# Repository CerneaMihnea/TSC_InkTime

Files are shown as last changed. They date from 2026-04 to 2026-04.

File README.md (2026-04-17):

# InkTime Watch
---

## Descriere generala

InkTime este un ceas inteligent bazat pe microcontroller-ul **nRF52840** , care utilizeaza un display E-Paper (cerneala electronica) pentru afisarea orei si a altor informatii. Proiectul include design complet de schematic, PCB pe 4 straturi si modelare 3D a ansamblului, realizate in Autodesk Fusion.

Principalele caracteristici:
- Microcontroller nRF52840 cu Bluetooth 5.0 si procesor ARM Cortex-M4
- Display E-Paper conectat prin SPI
- Accelerometru/IMU pentru detectia miscarii (step counter, wake-on-wrist)
- Baterie LiPo cu circuit de incarcare dedicat
- Regulator DC/DC pentru tensiune stabila de 3.3V
- Fuel Gauge pentru monitorizarea nivelului bateriei
- Driver haptic pentru feedback vibrotactil
- Protectie ESD pe linia USB-C
- Conectivitate USB-C pentru incarcare si programare
- 3 butoane fizice pentru interactiune

---

## Diagrama bloc

```
                         +-------------------+
                         |    Baterie LiPo   |
                         +--------+----------+
                                  |
                         +--------v----------+
                         |  LiPo Charger     |  <-- USB-C (5V / VBUS)
                         |  BQ25180YBGR      |
                         +--------+----------+
                                  | VBAT (3.7-4.2V)
                         +--------v----------+
                         |  Fuel Gauge        |  <-- I2C --> nRF52840
                         |  MAX17048G+T10     |
                         +--------+----------+
                                  |
                         +--------v----------+
                         |  DC/DC Regulator  |  <-- I2C --> nRF52840
                         |  RT6160AWSC       |
                         +--------+----------+
                                  | 3V3
          +-----------------------+-----------------------+
          |                       |                       |
+---------v---------+   +---------v---------+   +---------v---------+
|   nRF52840 (U1)   |   |  ESD Protection   |   |   Butoane (x3)    |
|   Microcontroller |   |  USBLC6-2SC6Y     |   |   EVP-AKE31A      |
+---------+---------+   +-------------------+   +-------------------+
          |
    +-----+------+------+------+
    |            |      |      |
+---v---+  +----v--+  +-v---+ +-v---------+
| SPI   |  |  I2C  |  | SWD | | GPIO/ANT  |
+---+---+  +---+---+  +-----+ +-----------+
    |          |
+---v---+   +--+--+--+--+
|E-Paper|   | IMU | Haptic|
|Display|   |BMA423|DRV2605|
+-------+   +-------+-----+
```

---

## Bill of Materials (BOM)

| Cantitate | Componenta | Descriere | Referinta | 
|:---:|:---:|:---:|:---:|
| 1 | nRF52840 | Microcontroller ARM Cortex-M4, BT 5.0 | U1 | 
| 1 | BQ25180YBGR | LiPo Charger IC, 8-DSBGA | IC1 | 
| 1 | DRV2605YZFR | Haptic Driver ERM/LRA, 9-BGA | IC2 |
| 1 | BMA423 | IMU Accelerometru triaxial 12-bit | IC3 |
| 1 | MAX17048G+T10 | Fuel Gauge 1-Cell ModelGauge | U3 | 
| 1 | RT6160AWSC | Buck-Boost DC/DC Regulator I2C, 15-WL-CSP | IC9 | 
| 1 | USBLC6-2SC6Y | ESD Protection TVS Diode, SOT-23-6 | D3 | 
| 1 | KH-TYPE-C-16P | Conector USB-C 16 pini | J4 |
| 1 | 503480-2400 | Conector FPC/FFC 0.5mm 24 circuite | J1 | 
| 1 | DMG2305UX-7 | P-Channel MOSFET 20V/4.2A SOT-23 | Q2 | 
| 1 | SI1308EDL-T1-GE3 | N-Channel MOSFET 30V/1.5A SC-70 | Q3 | 
| 3 | MBR0530 | Dioda Schottky 30V/500mA SOD-123 | D1, D2, D5 | 
| 3 | EVP-AKE31A | Buton tactil SMD ultra-subtire | SW_DN, SW_ENT, SW_UP | 
| 1 | 2450AT18B100E | Antena 2.45GHz SMD | ANT1 | 
| 1 | FTC252012SR47MBCA | Inductor SMD 0.47uH 2016 | L7 | 
| 1 | 744043680 | Inductor SMD 68uH WE-TPC | L5 |
| 1 | TC2030-IDC | Conector Tag-Connect 6 pini SWD | J2 |
| 1 | X1 (32MHz) | Crystal 32MHz 2016 SMD | X1 |
| 1 | X2 (32.768kHz) | Crystal 32.768kHz 3215 SMD | X2 | 
| ~50 | Condensatoare SMD | 0201/0402, diverse valori (1pF - 22uF) | Cx | 
| ~15 | Rezistoare SMD | 0201, diverse valori (2.2Ω - 10kΩ) | Rx |
| ~4 | Inductoare SMD | 0402, diverse valori (3.9nH - 15nH, 10uH) | Lx |
| 14 | Test Pad TP20R | Test pad-uri SMD 2mm | TP_* |
| 1 | Solder Jumper SJ | Jumper SMD | SJ1 |

---

## Descrierea functionalitatii hardware

## Funcționalitate hardware

### Interfețe de comunicație
- **I2C**: LiPo Charger, DC/DC, IMU, Fuel Gauge, Haptic Driver  
- **SPI**: E-Paper Display Connector  

### Componente și roluri

- **nRF52840**  
  Microcontroller-ul principal care coordonează întreaga funcționalitate a plăcii.

- **IMU (Accelerometru)**  
  Măsoară accelerația pe cele trei axe.

- **LiPo Charger**  
  Responsabil pentru încărcarea bateriei.

- **DC/DC**  
  Stabilizator de tensiune ce furnizează 3.3V stabili întregii plăci.

- **E-Paper Drive Circuit**  
  Controlează funcționarea display-ului E-Paper.

- **Fuel Gauge**  
  Monitorizează nivelul de încărcare al bateriei.

- **Haptic Driver**  
  Controlează vibrațiile actuatorului (shaker).

- **USB-C Connector**  
  Asigură interfața de conectare USB.

- **ESD Protection**  
  Protejează placa împotriva descărcărilor electrostatice.

---

## Pinii nRF52840

Tabelul de mai jos descrie alocarea pinilor microcontroller-ului:

| Pin nRF52840 | Semnal | Modul conectat | Interfata | Descriere |
|---|---|---|---|---|
| VDD | 3V3 | Alimentare | - | Alimentare la 3.3V |
| VSS | GND | Masa | - | Referinta de masa |
| P0.02/AIN0 | SCK | E-Paper Display | SPI | Clock serial SPI |
| P0.03/AIN1 | MOSI | E-Paper Display | SPI | Date catre display (Master Out Slave In) |
| P0.05/AIN3 | CS | E-Paper Display | SPI | Chip Select display |
| P0.15 | EPD_RST | E-Paper Display | GPIO | Reset display |
| P0.16 | EPD_DC | E-Paper Display | GPIO | Data/Command select |
| P0.17 | EPD_BUSY | E-Paper Display | GPIO | Stare ocupata display |
| P0.06 | SCL | IMU, LiPo Charger, DC/DC, Fuel Gauge, Haptic | I2C | Clock linie I2C |
| P0.07 | SDA | IMU, LiPo Charger, DC/DC, Fuel Gauge, Haptic | I2C | Date linie I2C |
| P0.08 | IMU_INT2 | BMA423 | GPIO | Intrerupere 2 accelerometru |
| P1.08 | IMU_INT1 | BMA423 | GPIO | Intrerupere 1 accelerometru |
| P0.10/NFC2 | FUELGAUGE_ALT | MAX17048 | GPIO | Alarma nivel scazut baterie |
| P0.11 | CHARGER_PG | BQ25180 | GPIO | Semnal Power Good charger |
| P0.12 | HAPTIC_EN | DRV2605 | GPIO | Enable driver haptic |
| P0.13 | BTN_UP | SW_UP | GPIO | Buton sus |
| P0.14 | BTN_ENT | SW_ENT | GPIO | Buton enter/confirmare |
| P1.02 | BTN_DN | SW_DN | GPIO | Buton jos |
| D+ | USB_DP | USB-C / ESD | USB | Date USB diferentiale pozitive |
| D- | USB_DM | USB-C / ESD | USB | Date USB diferentiale negative |
| VBUS | 5V USB | LiPo Charger | - | Alimentare 5V din USB |
| SWDIO | SWDIO | TC2030-IDC (J2) | SWD | Date programare/debug |
| SWDCLK | SWDCLK | TC2030-IDC (J2) | SWD | Clock programare/debug |
| SWO | SWO | TC2030-IDC (J2) | SWD | Trace output |
| P0.18/RESET | RESET | TC2030-IDC (J2) | GPIO | Reset hardware microcontroller |
| ANT | RF | 2450AT18B100E | RF | Antena Bluetooth 2.4GHz |
| XC1, XC2 | XTAL_32M | X1 (32 MHz) | Clock | Sursa de ceas principala |
| XL1, XL2 | XTAL_32K | X2 (32.768 kHz) | Clock | Sursa de ceas RTC (low power) |
| DEC1-DEC5 | GND | - | - | Condensatoare decuplare regulatoare interne |

---

## Design PCB si modelare 3D

### Stackup PCB — 4 straturi

Placa a fost realizata pe **4 straturi** pentru a asigura integritate de semnal buna si o rutare curata:

| Strat | Rol |
|---|-----|
| Top (L1) | Rutare semnal + componente SMD |
| L2 | Plan de masa (GND) |
| L3 | Plan de 3.3V (VCC) |
| Bottom (L4) | Rutare semnal secundar |

Avantajele acestui stackup:
- Planul de masa L2 ofera un return path scurt pentru toate semnalele de pe L1
- Planul de 3.3V L3 reduce impedanta de alimentare si EMI
- Via-urile de semnal au return path minim intre straturi adiacente

### Decizii de design notabile

**Antena si decupaj PCB**: Antena 2450AT18B100E este pozitionata in coltul inferior al placii. Sub jumatatea neconectata electric a antenei, s-a realizat un **decupaj al substratului** (cutout) pentru a imbunatati performanta de radiatie si a evita absorbtia de semnal RF de catre materialul FR4.

**Via-in-pad**: Pentru componentele BGA (BQ25180, RT6160, DRV2605, MAX17048) cu pitch mic, s-au folosit **via-in-pad** — via-uri plasate direct sub pad-urile componentelor. Aceasta tehnica permite rutarea semnalelor in spatiu limitat, dar necesita umplere cu rasina (plugged vias) pentru a asigura planitate la lipire.

**Test pad-uri**: Sunt prevazute 14 test pad-uri (TP20R) pentru toate semnalele importante: 3V3, VBAT, GND, SDA, SCL, SWDCLK, SWDIO, SWO, RESET, VREG. Acestea faciliteaza testarea si depanarea dupa asamblare.

**Conexiuni baterie si shaker**: Bateria LiPo si motorul haptic (shaker) sunt conectate la PCB prin fire sudate pe test pad-urile dedicate (TP_VBAT, TP_VBAT_GND, respectiv pad-urile haptic driver-ului).

### Modelare 3D

Modelarea 3D a ansamblului ceasului a fost realizata in **Autodesk Fusion** si include:

- **PCB 3D** cu toate componentele plasate si orientate corect
- **Baterie LiPo** — model la nivel mediu de detaliu, cu fire de legatura rosu (+) si negru (-)
- **Display E-Paper** — model cu cadru verde si suprafata activa neagra, cu conector FPC/FFC
- **Shaker (motor haptic)** — model cilindric cu fire rosu si albastru
- **Carcasa** — carcasa inferioara si cadru superior de retentie display, fabricate din material negru
- **Exploded View** — vedere explodata verticala a ansamblului complet
- **Animatie** exploded view (disponibila in folderul Mechanical)

---

## Imagini

### Schematic

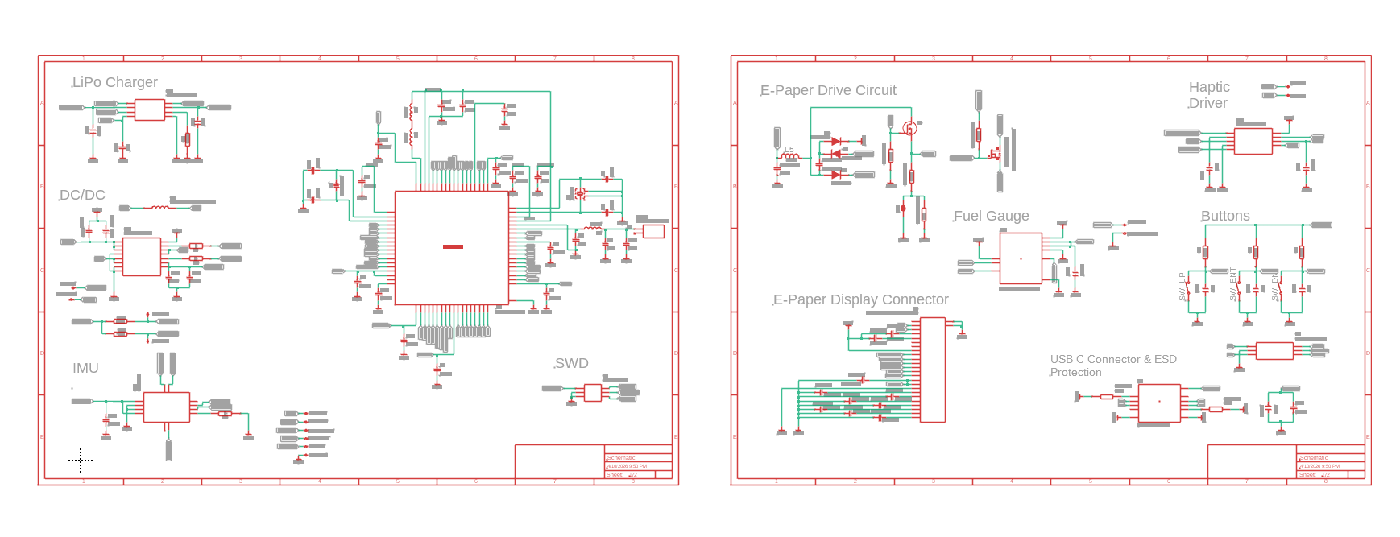
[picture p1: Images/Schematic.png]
Schematic


### PCB 2D

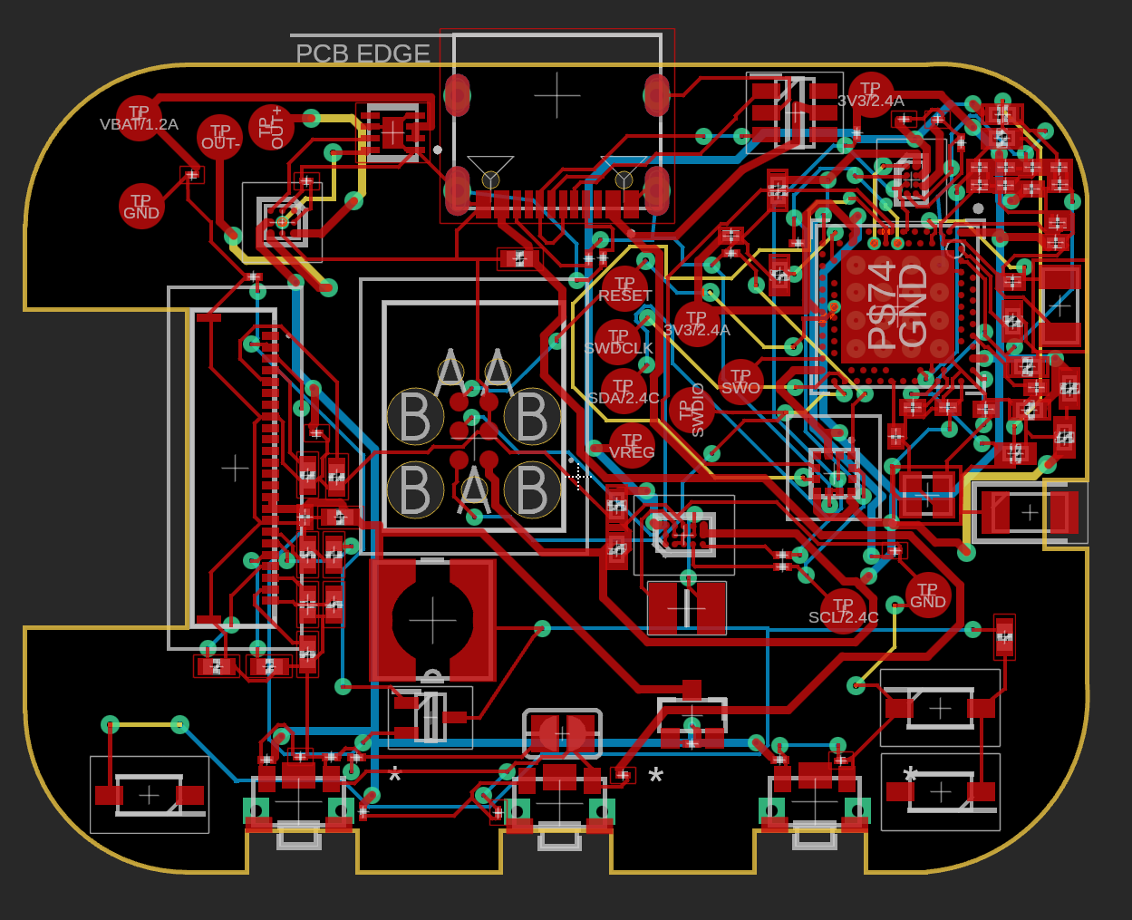
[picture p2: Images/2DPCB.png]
PCB 2D


### PCB 3D

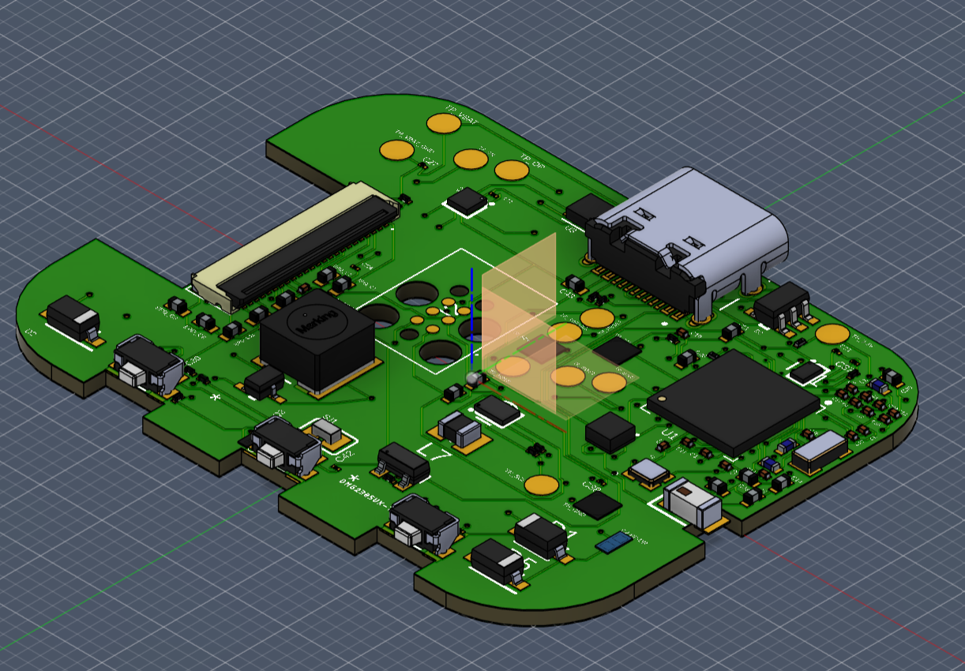
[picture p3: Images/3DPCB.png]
PCB 3D


### Baterie

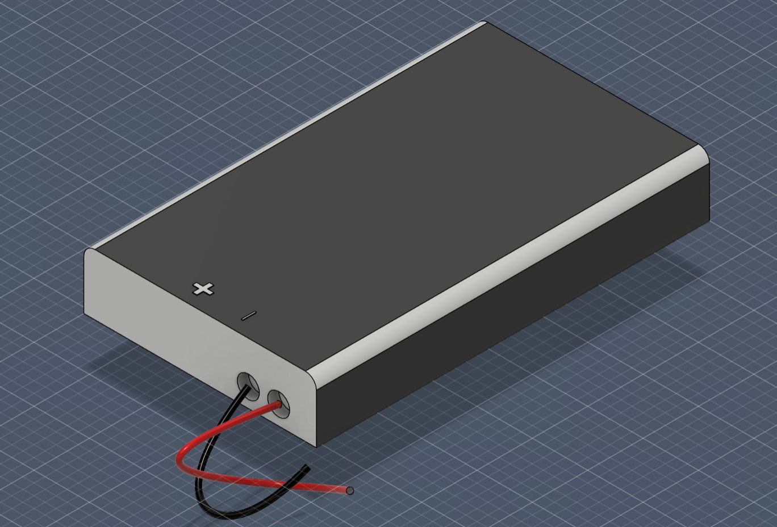
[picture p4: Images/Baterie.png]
Baterie


### Display E-Paper

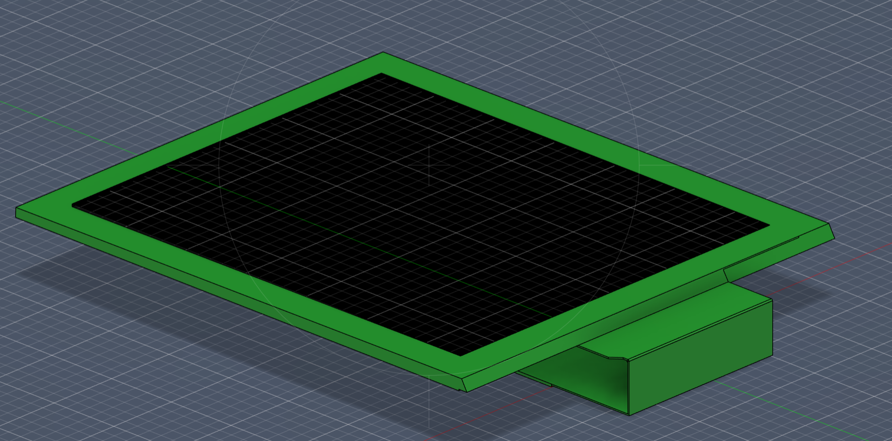
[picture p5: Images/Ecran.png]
Display


### Shaker (Motor Haptic)

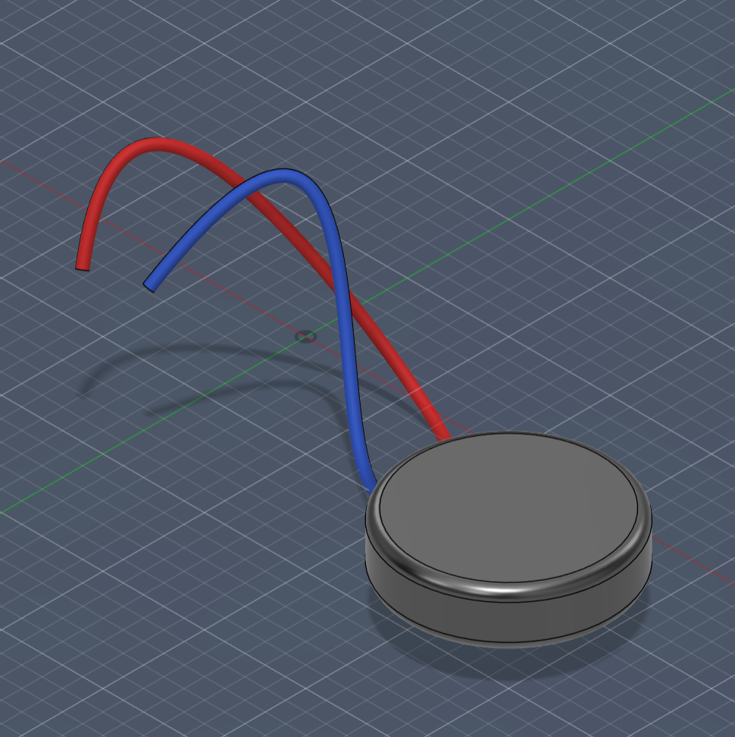
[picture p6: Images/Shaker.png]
Shaker


### Exploded View

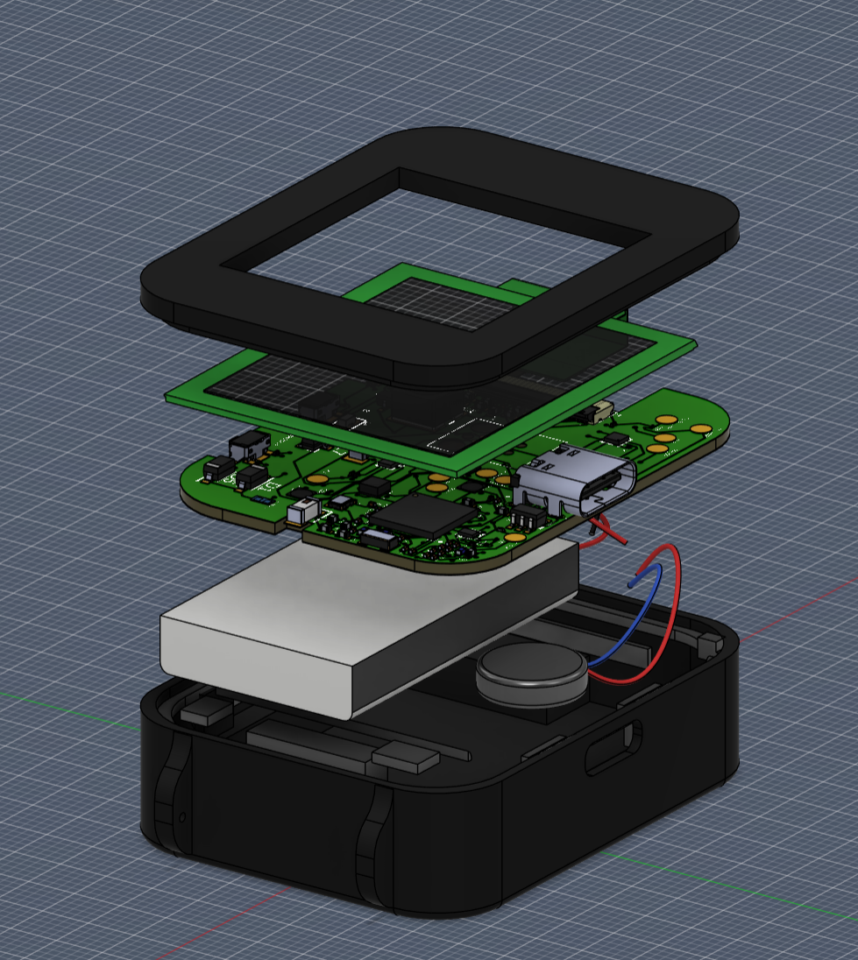
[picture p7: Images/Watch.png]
Exploded View


## Diagrama de sistem — SVG

Diagrama bloc interactiva este disponibila in fisierul `inktime_diagram.svg` din radacina proiectului.

---

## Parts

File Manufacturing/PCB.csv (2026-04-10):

Qty | Value | Device | Package | Parts | Description | ARROW_PART_NUMBER | ARROW_PRICE-STOCK | AVAILABILITY | CHECK_PRICES | COPYRIGHT | DESCRIPTION | DIGI-KEY_PART_NUMBER_1 | DIGI-KEY_PART_NUMBER_2 | DIGI-KEY_PART_NUMBER_3 | HEIGHT | JLCPCB | MANUFACTURER_NAME | MANUFACTURER_PART_NUMBER | MF | MFR_NAME | MOUSER_PART_NUMBER | MOUSER_PRICE-STOCK | MP | PACKAGE | POPULARITY | PRICE | PROD_ID | PURCHASE-URL | SNAPEDA_LINK | TP_SIGNAL_NAME | VALUE
1 |  | ESP32_C6_LIBRARY_7_JUMPER_SJ | ESP32_C6_LIBRARY_7_JUMPER_SJ | SJ1 | SMD solder JUMPER |  |  |  |  |  |  |  |  |  |  |  |  |  |  |  |  |  |  |  | 3
3 | 0 | CPF0201D7K68C1_CPF0201D7K68C1 | CPF0201D7K68C1_0201 | R2, R3, R4 | 7.68k 0201 Thin Film Surface Mount Fixed Resistor +/-0.5% 0.031W CPF0201D7K68C1
4 | 0.1uF | GRM011R60J152KE01L_2_GRM011R60J152KE01L | GRM011R60J152KE01L_2_CAPC0201X13N | C23, C27, C34, C42 | Check availability |  |  | In Stock | https://www.snapeda.com/parts/GRM011R60J152KE01L/Murata/view-part/?ref=eda |  | SMD Capacitor X5R(EIA) with Capacitance: 1500pF Tol. 10%. Rated Voltage: 6.3Vdc |  |  |  |  |  |  |  | Murata |  |  |  | GRM011R60J152KE01L | 0201 Murata |  | None |  |  | https://www.snapeda.com/parts/GRM011R60J152KE01L/Murata/view-part/?ref=snap
1 | 0.1uF/50V | NORDIC_NRF_3_CAPACITOR_0201_L | NORDIC_NRF_3_RESC0201_L | EPD_C5 | Generic chip capacitor
1 | 0.47 | CPF0201D7K68C1_CPF0201D7K68C1 | CPF0201D7K68C1_0201 | R1_EP_DR | 7.68k 0201 Thin Film Surface Mount Fixed Resistor +/-0.5% 0.031W CPF0201D7K68C1
1 | 1.0µF | NORDIC_NRF_3_CAPACITOR_0402_L | NORDIC_NRF_3_RESC0402_L | C15 | Generic chip capacitor
5 | 100nF | NORDIC_NRF_3_CAPACITOR_0201_L | NORDIC_NRF_3_RESC0201_L | C5, C7, C8, C12, C19 | Generic chip capacitor
1 | 100pF | NORDIC_NRF_3_CAPACITOR_0201_L | NORDIC_NRF_3_RESC0201_L | C11 | Generic chip capacitor
6 | 10K | CPF0201D7K68C1_CPF0201D7K68C1 | CPF0201D7K68C1_0201 | R2_EP_DR, R5, R7, R8, R9, R_PWR_EPD | 7.68k 0201 Thin Film Surface Mount Fixed Resistor +/-0.5% 0.031W CPF0201D7K68C1
1 | 10uF | GRM011R60J152KE01L_2_GRM011R60J152KE01L | GRM011R60J152KE01L_2_CAPC0201X13N | C38 | Check availability |  |  | In Stock | https://www.snapeda.com/parts/GRM011R60J152KE01L/Murata/view-part/?ref=eda |  | SMD Capacitor X5R(EIA) with Capacitance: 1500pF Tol. 10%. Rated Voltage: 6.3Vdc |  |  |  |  |  |  |  | Murata |  |  |  | GRM011R60J152KE01L | 0201 Murata |  | None |  |  | https://www.snapeda.com/parts/GRM011R60J152KE01L/Murata/view-part/?ref=snap
1 | 10uF | NORDIC_NRF_3_CAPACITOR_0402_L | NORDIC_NRF_3_RESC0402_L | C24 | Generic chip capacitor
1 | 10uF | PERFECT_0402_CAP_0402 | PERFECT_0402_0402 | C1-EP-DR | 0402 (1005 Metric)
1 | 10µH | NORDIC_NRF_2_INDUCTOR_0402_L | NORDIC_NRF_2_RESC0402_L | L2 | Generic chip inductor
4 | 12pF | NORDIC_NRF_3_CAPACITOR_0201_L | NORDIC_NRF_3_RESC0201_L | C1, C2, C17, C18 | Generic chip capacitor
1 | 15nH | NORDIC_NRF_2_INDUCTOR_0402_L | NORDIC_NRF_2_RESC0402_L | L3 | Generic chip inductor
2 | 1pF | NORDIC_NRF_3_CAPACITOR_0201_L | NORDIC_NRF_3_RESC0201_L | C3, C4 | Generic chip capacitor
5 | 1uF | GRM011R60J152KE01L_2_GRM011R60J152KE01L | GRM011R60J152KE01L_2_CAPC0201X13N | C29, C30, C31, C32, C37 | Check availability |  |  | In Stock | https://www.snapeda.com/parts/GRM011R60J152KE01L/Murata/view-part/?ref=eda |  | SMD Capacitor X5R(EIA) with Capacitance: 1500pF Tol. 10%. Rated Voltage: 6.3Vdc |  |  |  |  |  |  |  | Murata |  |  |  | GRM011R60J152KE01L | 0201 Murata |  | None |  |  | https://www.snapeda.com/parts/GRM011R60J152KE01L/Murata/view-part/?ref=snap
1 | 1uF | NORDIC_NRF_3_CAPACITOR_0402_L | NORDIC_NRF_3_RESC0402_L | C39 | Generic chip capacitor
9 | 1uF/50V | PERFECT_0402_CAP_0402 | PERFECT_0402_0402 | EPD_C1, EPD_C2, EPD_C6, EPD_C7, EPD_C8, EPD_C9, EPD_C10, EPD_C11, EPD_C12 | 0402 (1005 Metric)
1 | 2.2 | CPF0201D7K68C1_CPF0201D7K68C1 | CPF0201D7K68C1_0201 | R_TYPE_SEL | 7.68k 0201 Thin Film Surface Mount Fixed Resistor +/-0.5% 0.031W CPF0201D7K68C1
3 | 2025-10-22_07-23-44_LIBRARY_EVP-AKE31ASW_EVP-AKE31A_PAN | 2025-10-22_07-23-44_LIBRARY_EVP-AKE31ASW_EVP-AKE31A_PAN | 2025-10-22_07-23-44_LIBRARY_SW_EVP-AKE31A_PAN | SW_DN, SW_ENT, SW_UP |  |  |  |  |  | Copyright (C) 2025 Ultra Librarian. All rights reserved. |  | P123437TR-ND | P123437CT-ND | P123437DKR-ND |  |  | Panasonic | EVP-AKE31A
1 | 20V/4.2A/52mO/1.4W | ESP32_C6_LIBRARY_4_ESP32_WROVER_SPARKFUN-DISCRETESEMI_MOSFET_PCH-DMG2305UX-7 | ESP32_C6_LIBRARY_4_ESP32_C6_LIBRARY_4_ESP32_C6_LIBRARY_4_ESP32_C6_LIBRARY_4_ESP32_WROVER_SPARKFUN-DISCRETESEMI_SOT23-3 | DMG2305UX-7 | P-channel MOSFETs |  |  |  |  |  |  |  |  |  |  |  |  |  |  |  |  |  |  |  |  |  | TRAN-14388 |  |  |  | 20V/4.2A/52mO/1.4W
2 | 22uF | NORDIC_NRF_3_CAPACITOR_0402_L | NORDIC_NRF_3_RESC0402_L | C25, C33 | Generic chip capacitor
1 | 2450AT18B100E | 2450AT18B100E_2450AT18B100E | 2450AT18B100E_ANTC3216X140N | ANT1 | Antennas 2.45GHz ANTENNA | 2450AT18B100E | https://www.arrow.com/en/products/2450at18b100e/johanson-dielectrics?utm_currency=USD&region=nac |  |  |  | Antennas 2.45GHz ANTENNA |  |  |  | 1.4mm |  | JOHANSON TECHNOLOGY | 2450AT18B100E |  |  | 609-2450AT18B100E | https://www.mouser.co.uk/ProductDetail/Johanson-Technology/2450AT18B100E?qs=yCnrNFeXz%252Bh5MFsFIXGZGA%3D%3D
1 | 3.9nH | NORDIC_NRF_2_INDUCTOR_0402_L | NORDIC_NRF_2_RESC0402_L | L1 | Generic chip inductor
1 | 32.768kHz | NORDIC_NRF_1_XTAL_32KHZ | NORDIC_NRF_1_XTAL_3215_N | X2
1 | 32MHz | NORDIC_NRF_XTAL_32MHZ | NORDIC_NRF_BT-XTAL_2016_N | X1
1 | 3K3 | ERA-1AEB3401C_CPF0201D7K68C1 | ERA-1AEB3401C_0201 | R17 | 7.68k 0201 Thin Film Surface Mount Fixed Resistor +/-0.5% 0.031W CPF0201D7K68C1
1 | 3k3 | ERA-1AEB3401C_CPF0201D7K68C1 | ERA-1AEB3401C_0201 | R18 | 7.68k 0201 Thin Film Surface Mount Fixed Resistor +/-0.5% 0.031W CPF0201D7K68C1
1 | 4.7uF | PERFECT_0402_CAP_0402 | PERFECT_0402_0402 | C43 | 0402 (1005 Metric)
1 | 4.7uF/25V | PERFECT_0402_CAP_0402 | PERFECT_0402_0402 | C2-EP-DR | 0402 (1005 Metric)
4 | 4.7µF | NORDIC_NRF_3_CAPACITOR_0402_L | NORDIC_NRF_3_RESC0402_L | C6, C14, C20, C21 | Generic chip capacitor
1 | 47nF | NORDIC_NRF_3_CAPACITOR_0201_L | NORDIC_NRF_3_RESC0201_L | C16 | Generic chip capacitor
1 | 503480-2400_503480-2400 | 503480-2400_503480-2400 | 503480-2400_5034802400 | J1 | FFC & FPC Connectors 0.5mm FPC RA SMT Dual Contact 24Ckt |  |  |  |  |  | FFC & FPC Connectors 0.5mm FPC RA SMT Dual Contact 24Ckt |  |  |  | 1.87mm |  | Molex | 503480-2400 |  |  | 538-503480-2400 | https://www.mouser.co.uk/ProductDetail/Molex/503480-2400?qs=OAhjpuo3Vu7efIoxFh9AOw%3D%3D
2 | 5K1 | CPF0201D7K68C1_CPF0201D7K68C1 | CPF0201D7K68C1_0201 | R1_USB, R2_USB | 7.68k 0201 Thin Film Surface Mount Fixed Resistor +/-0.5% 0.031W CPF0201D7K68C1
1 | 68uH | ESP32_C6_LIBRARY_2_744043680IND_4828-WE-TPC_WRE | ESP32_C6_LIBRARY_2_IND_4828-WE-TPC_WRE | L5 |  |  |  |  |  | Copyright (C) 2024 Ultra Librarian. All rights reserved. |  |  |  |  |  |  |  | 744043680 |  | Wurth Electronics
1 | 820pF | NORDIC_NRF_3_CAPACITOR_0201_L | NORDIC_NRF_3_RESC0201_L | C9 | Generic chip capacitor
1 | BMA421 | BMA423_BMA423 | BMA423_BMA423 | IC3 | Accelerometers Triaxial low-g 12bit Acceleration Sensor | BMA423 | https://www.arrow.com/en/products/bma423/bosch |  |  |  | Accelerometers Triaxial low-g 12bit Acceleration Sensor |  |  |  | 1mm |  | BOSCH | BMA423 |  |  | 262-BMA423 | https://www.mouser.co.uk/ProductDetail/Bosch-Sensortec/BMA423?qs=HXFqYaX1Q2xC%252BSgeGoX3mg%3D%3D
1 | BQ25180YBGR | BQ25180YBGR_BQ25180YBGR | BQ25180YBGR_BGA8C40P2X4_100X155X50 | IC1 | Charger IC Lithium Ion/Polymer, Lithium Iron Phosphate 8-DSBGA (1.6x1.1) | BQ25180YBGR | https://www.arrow.com/en/products/bq25180ybgr/texas-instruments?utm_currency=USD&region=nac |  |  |  | Charger IC Lithium Ion/Polymer | Lithium Iron Phosphate 8-DSBGA (1.6x1.1) |  |  |  | 0.5mm |  | Texas Instruments | BQ25180YBGR |  |  | 595-BQ25180YBGR | https://www.mouser.co.uk/ProductDetail/Texas-Instruments/BQ25180YBGR?qs=doiCPypUmgEWjAK%252BJAX6Tw%3D%3D
1 | DRV2605YZFR | DRV2605YZFR_DRV2605YZFR | DRV2605YZFR_BGA9C50P3X3_144X144X62 | IC2 | Haptic Driver for ERM/LRA with Built-In Library and Smart Loop Architecture | DRV2605YZFR | https://www.arrow.com/en/products/drv2605yzfr/texas-instruments?region=nac |  |  |  | Haptic Driver for ERM/LRA with Built-In Library and Smart Loop Architecture |  |  |  | 0.625mm |  | Texas Instruments | DRV2605YZFR
1 | FTC252012SR47MBCA | MLP2016SR47MT0S1_FTC252012SR47MBCA | MLP2016SR47MT0S1_INDC2016X100N | L7 | SMD / SMT Inductors (Coils), L=0.47?H, L x W x T : |  |  |  |  |  | SMD / SMT Inductors (Coils) | L=0.47?H | L x W x T : |  |  |  | 1mm | https://jlcpcb.com/partdetail/6763488-FTC252012SR47MBCA/C5832368 | TDK | FTC252012SR47MBCA
14 | HECTOR_WATCH_1_TPTP20R | HECTOR_WATCH_1_TPTP20R | HECTOR_WATCH_1_TP20R | TP_3.3V, TP_3V3, TP_GND, TP_ON, TP_OP, TP_RESET, TP_SCL, TP_SDA, TP_SWDCLK, TP_SWIO, TP_SWO, TP_VBAT, TP_VBAT_GND, TP_VREG | Test pad |  |  |  |  |  |  |  |  |  |  |  |  |  |  |  |  |  |  |  | 2
1 | KH-TYPE-C-16P | KH-TYPE-C-16P_KH-TYPE-C-16P | KH-TYPE-C-16P_KINGHELM_KH-TYPE-C-16P | J4 | Check availability |  |  | Not in stock | https://www.snapeda.com/parts/KH-TYPE-C-16P/Kinghelm/view-part/?ref=eda |  |  |  |  |  |  |  |  |  | kinghelm |  |  |  | KH-TYPE-C-16P | None |  | None |  |  | https://www.snapeda.com/parts/KH-TYPE-C-16P/Kinghelm/view-part/?ref=snap
1 | MAX17048G+T10 | ESP32_C6_LIBRARY_MAX17048G+T10 | ESP32_C6_LIBRARY_SON50P200X200X80-9N | U3 | Check availability |  |  | In Stock | https://www.snapeda.com/parts/MAX17048G+T10/Analog+Devices/view-part/?ref=eda |  | 3µA 1-Cell/2-Cell Fuel Gauge with ModelGauge |  |  |  |  |  |  |  | Analog Devices |  |  |  | MAX17048G+T10 | TDFN-8 Maxim |  | None |  | https://www.snapeda.com/api/url_track_click_mouser/?unipart_id=329239&manufacturer=Analog Devices&part_name=MAX17048G+T10&search_term=None | https://www.snapeda.com/parts/MAX17048G+T10/Analog+Devices/view-part/?ref=snap
3 | MBR0530 | ESP32_C6_LIBRARY_5_MBR0530 | ESP32_C6_LIBRARY_5_SOD3716X135N | D1, D2, D5 | ON SEMICONDUCTOR - MBR0530 - DIODE, SCHOTTKY, 0.5A, 30V, SOD-123 |  |  | In Stock | https://www.snapeda.com/parts/MBR0530/Onsemi/view-part/?ref=eda |  | Diode Schottky 30 V 500mA Surface Mount SOD-123 |  |  |  |  |  |  |  | ON Semiconductor |  |  |  | MBR0530 | SOD-123-2 ON Semiconductor |  | None |  | https://www.snapeda.com/api/url_track_click_mouser/?unipart_id=179458&manufacturer=ON Semiconductor&part_name=MBR0530&search_term=None | https://www.snapeda.com/parts/MBR0530/Onsemi/view-part/?ref=snap
3 | N.C. | NORDIC_NRF_3_CAPACITOR_0201_L | NORDIC_NRF_3_RESC0201_L | C10, C13, C22 | Generic chip capacitor
1 | NRF52840_QF | NORDIC_NRF_4_NRF52840_QF | NORDIC_NRF_4_AQFN50P700X700X85_HS-74N | U1 | nRF52840
1 | RT6160AWSC | RT6160AWSC_RT6160AWSC | RT6160AWSC_BGA15C40P3X5_140X230X60 | IC9 | Buck-Boost Regulator Positive Output Step-Up/Step-Down I2C DC-DC Controller IC 15-WL-CSP (BSC) (1.4x2.3) |  |  |  |  |  | Buck-Boost Regulator Positive Output Step-Up/Step-Down I2C DC-DC Controller IC 15-WL-CSP (BSC) (1.4x2.3) |  |  |  | 0.6mm |  | RICHTEK | RT6160AWSC |  |  | 835-RT6160AWSC | https://www.mouser.co.uk/ProductDetail/Richtek/RT6160AWSC?qs=amGC7iS6iy%2FLd9PSoixZXQ%3D%3D
1 | SI1308EDL-T1-GE3 | ESP32_C6_LIBRARY_6_SI1308EDL-T1-GE3 | ESP32_C6_LIBRARY_6_SOT65P210X110-3N | Q3 | MOSFET N-Ch 30V 1.5A TrenchFET SC70 Vishay Si1308EDL-T1-GE3 N-channel MOSFET Transistor, 1.5 A, 30 V, 3-Pin SC-70 |  |  | In Stock | https://www.snapeda.com/parts/SI1308EDL-T1-GE3/Vishay+Siliconix/view-part/?ref=eda |  | Si1308EDL-T1-GE3 N-channel MOSFET Transistor | 1.5 A | 30 V | 3-Pin SC-70 | Siliconix / Vishay SI1308EDL-T1-GE3 |  |  |  |  |  |  |  | Vishay Siliconix |  |  |  | SI1308EDL-T1-GE3 | SOT-323 Vishay Semiconductor |  | None |  | https://www.snapeda.com/api/url_track_click_mouser/?unipart_id=274603&manufacturer=Vishay Siliconix&part_name=SI1308EDL-T1-GE3&search_term=None
1 | TC2030-IDC | TC2030-IDC_TC2030-IDC | TC2030-IDC_TC2030IDC | J2 | CABLE ADAPTER 6 POS |  |  |  |  |  | CABLE ADAPTER 6 POS |  |  |  | 19mm |  | Tag Connect | TC2030-IDC
1 | USBLC6-2SC6Y | ESP32_C6_LIBRARY_3_USBLC6-2SC6Y | ESP32_C6_LIBRARY_3_SOT95P280X145-6N | D3 | Low Cap. ESD Protection Auto SOT-23-6 STMicroelectronics USBLC6-2SC6Y, Dual Uni-Directional TVS Diode Array, 6-Pin SOT-23 |  |  | In Stock | https://www.snapeda.com/parts/USBLC6-2SC6Y/STMicroelectronics/view-part/?ref=eda |  | 17V Clamp 5A (8/20µs) Ipp Tvs Diode Surface Mount SOT-23-6 |  |  |  |  |  |  |  | STMicroelectronics |  |  |  | USBLC6-2SC6Y | SOT-23-6 STMicroelectronics |  | None |  |  | https://www.snapeda.com/parts/USBLC6-2SC6Y/STMicroelectronics/view-part/?ref=snap

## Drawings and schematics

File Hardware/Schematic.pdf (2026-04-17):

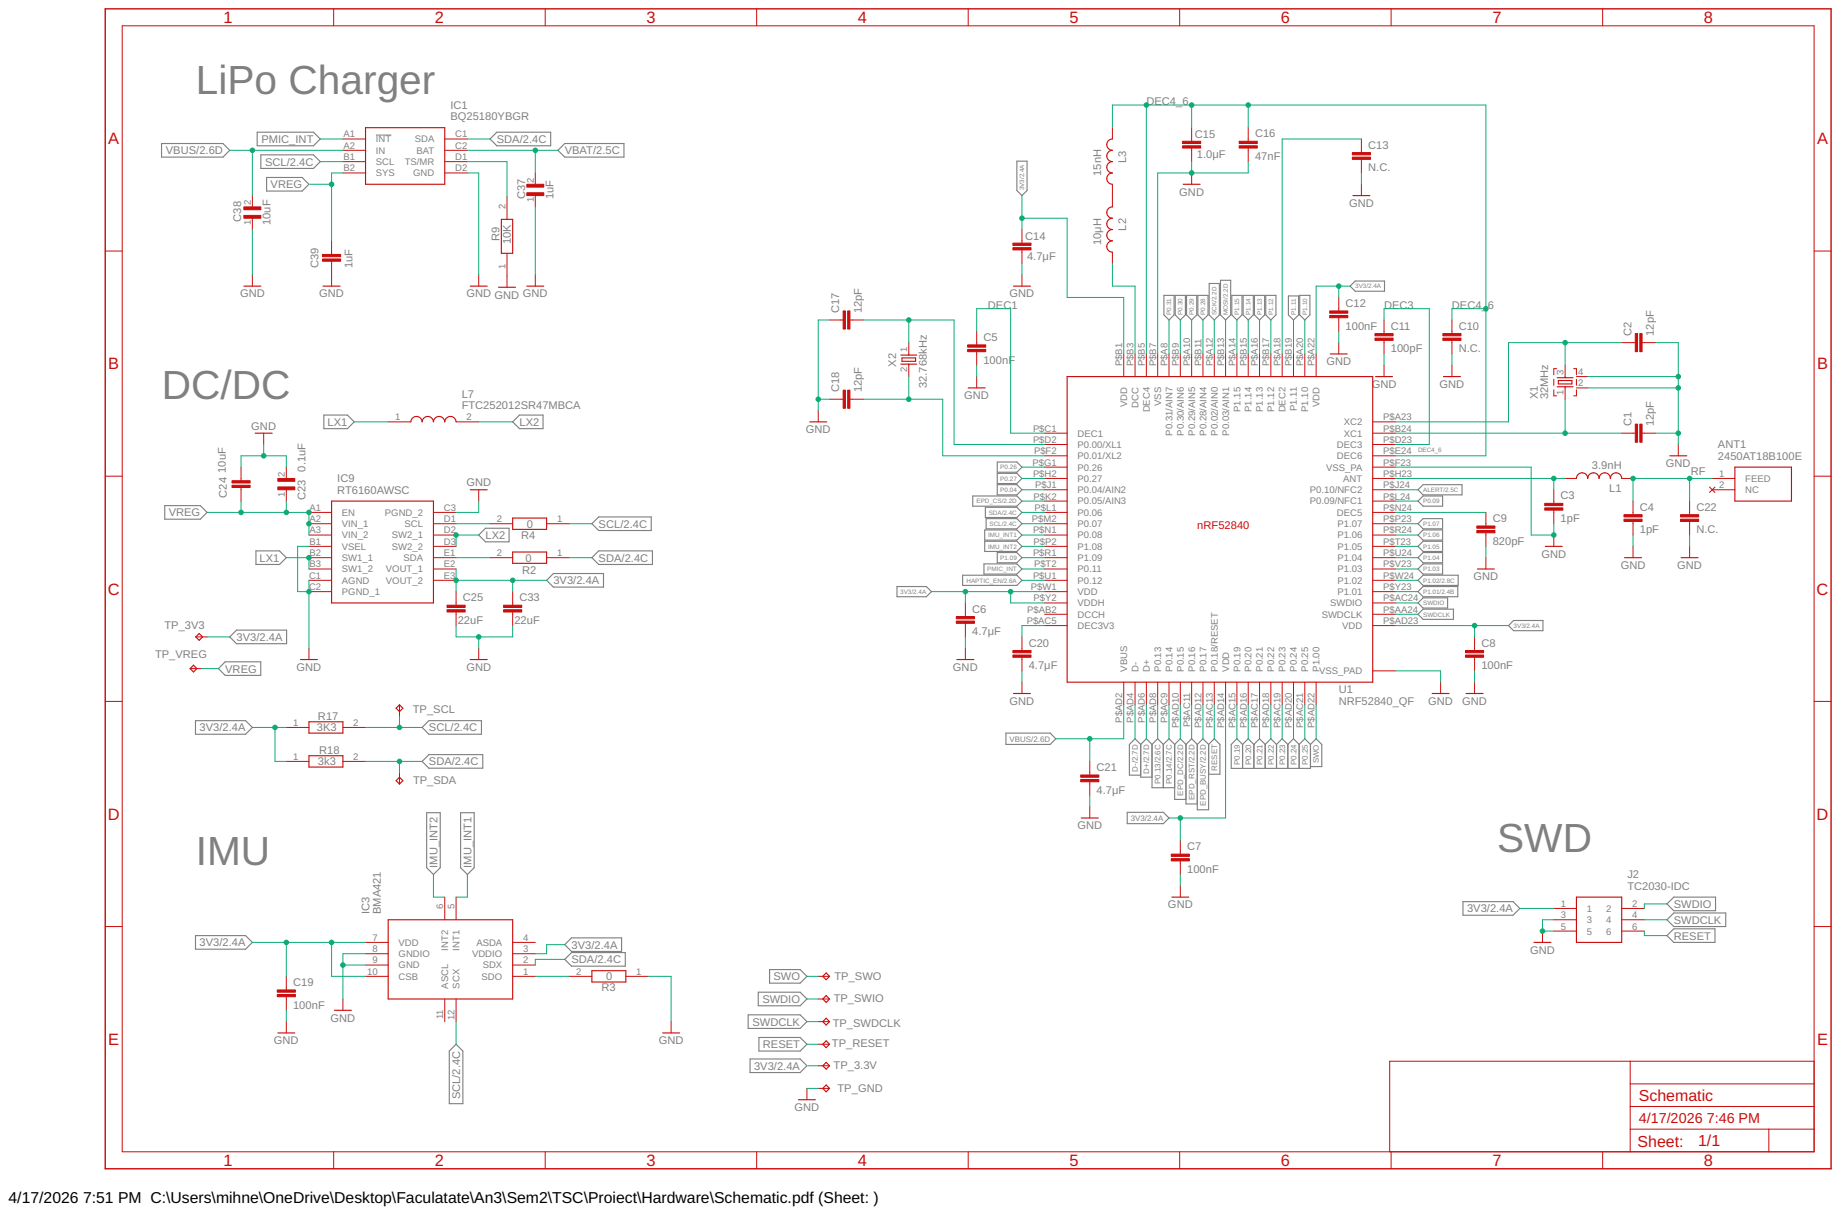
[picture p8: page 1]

10uF GND GND GND GND GND

4/17/2026 7:51 PM C:\Users\mihne\OneDrive\Desktop\Faculatate\An3\Sem2\TSC\Proiect\Hardware\Schematic.pdf (Sheet: )

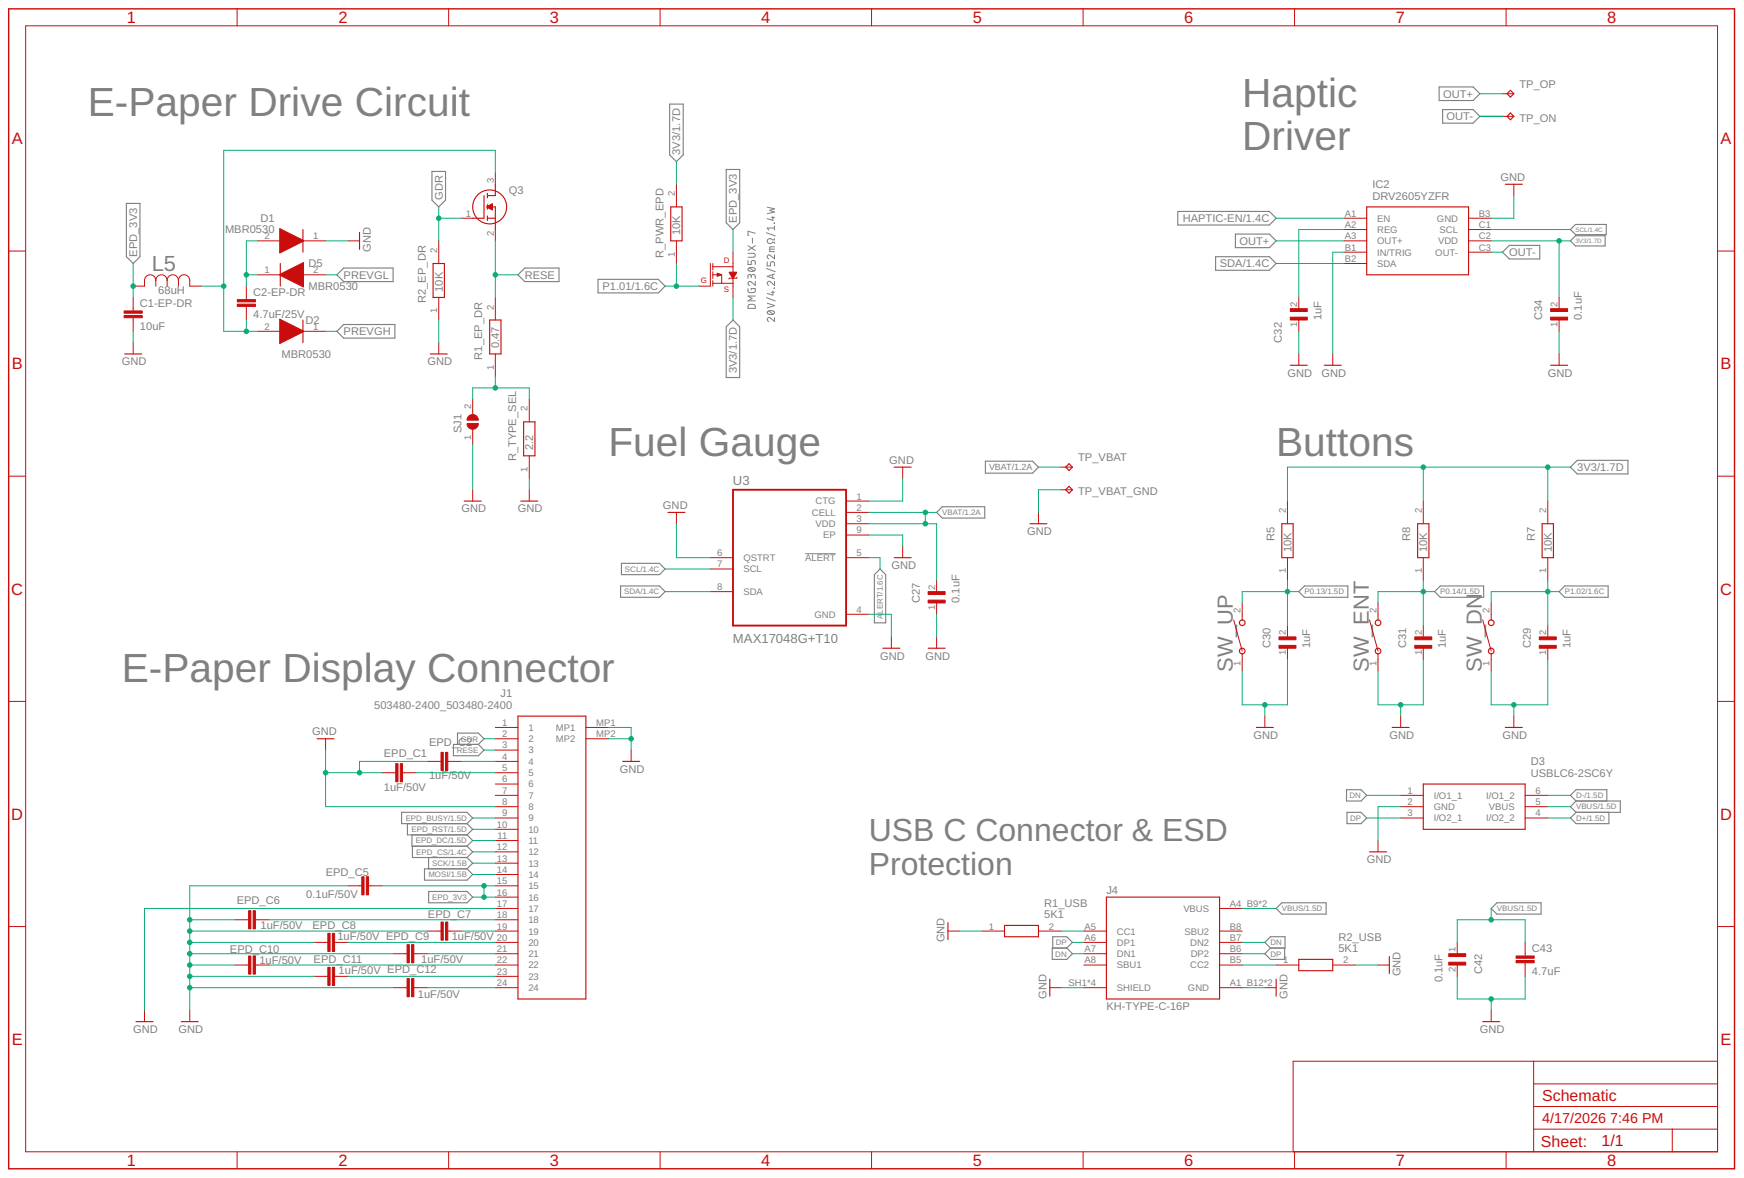
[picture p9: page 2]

E-Paper Drive Circuit | TP_OP

1uF/50V EPD_C8 | 19

1uF/50V EPD_C9 | 1uF/50V 20

EPD_C10 | | 21
1uF/50V EPD_C11 | 1uF/50V 22

1uF/50V EPD_C12 23

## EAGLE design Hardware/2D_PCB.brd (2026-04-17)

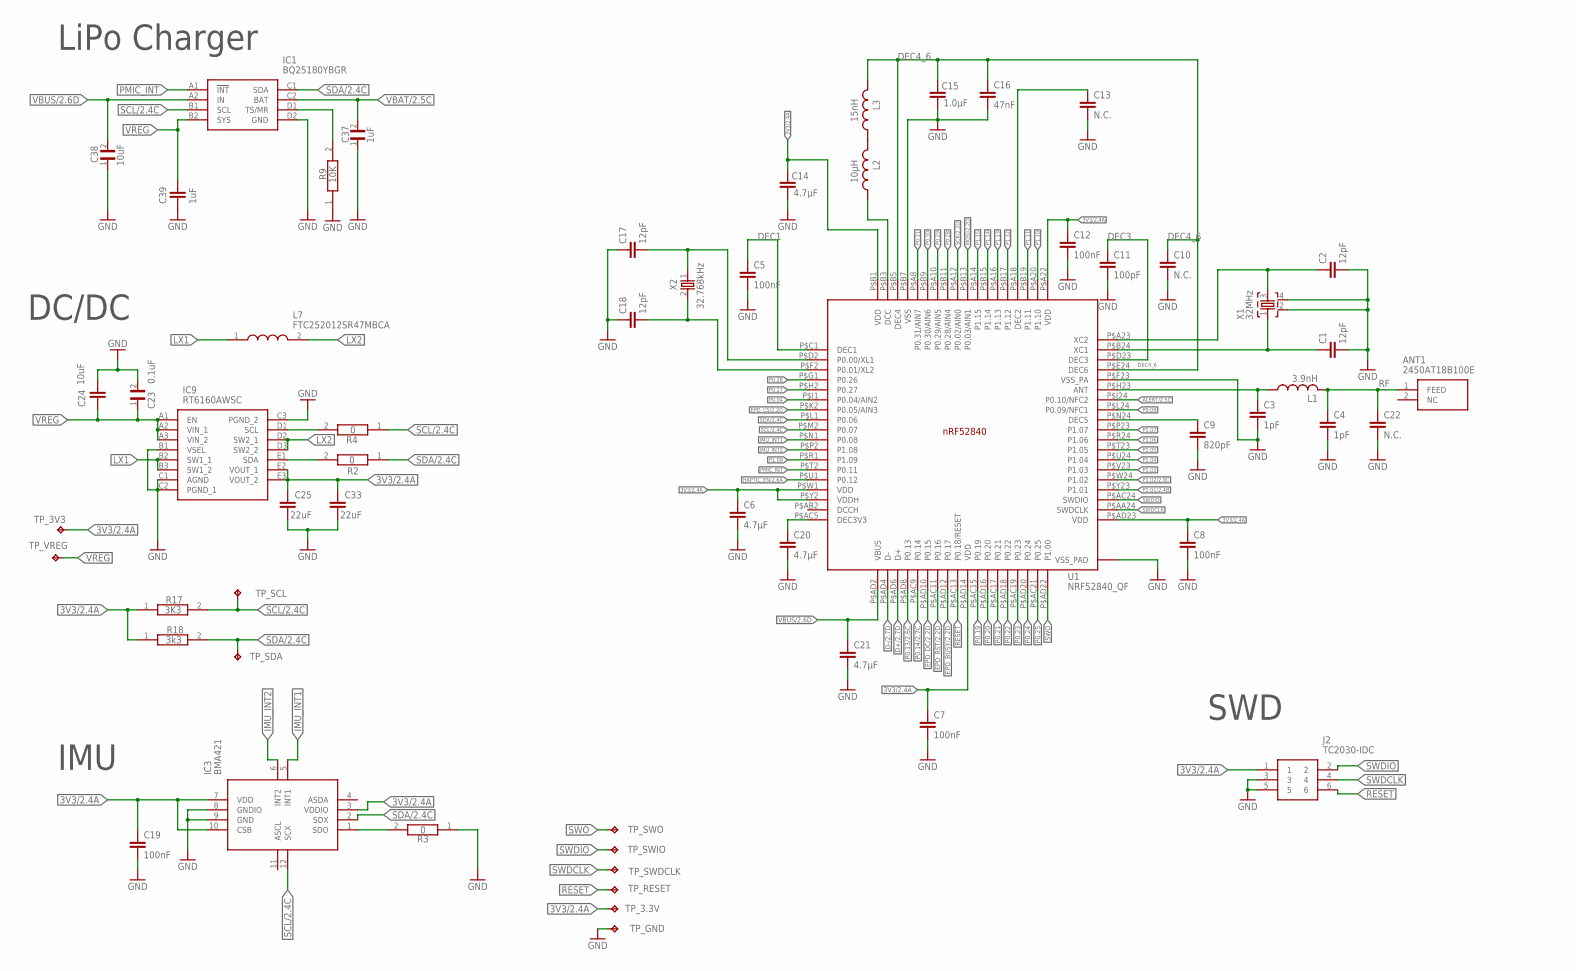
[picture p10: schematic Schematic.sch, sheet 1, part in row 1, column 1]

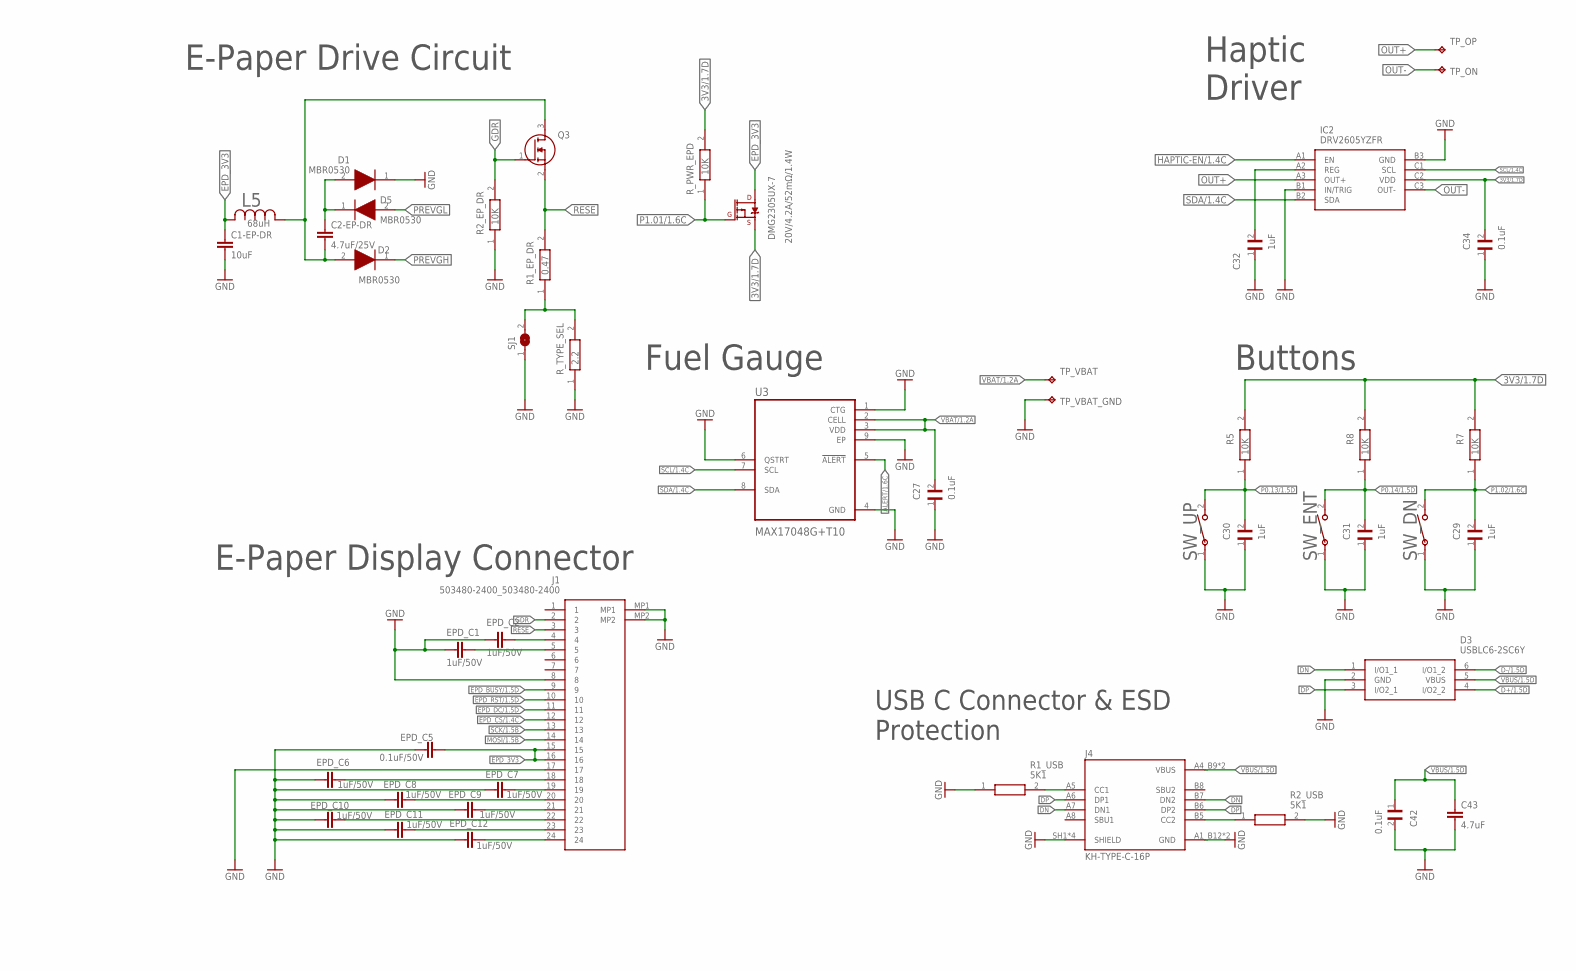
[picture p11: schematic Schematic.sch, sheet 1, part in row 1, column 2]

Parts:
ANT1: 2450AT18B100E; 2450AT18B100E_ANTC3216X140N
C1, C2, C17, C18: 12pF; NORDIC_NRF_3_RESC0201_L
C1-EP-DR: 10uF; PERFECT_0402_0402
C2-EP-DR: 4.7uF/25V; PERFECT_0402_0402
C3, C4: 1pF; NORDIC_NRF_3_RESC0201_L
C5, C7, C8, C12, C19: 100nF; NORDIC_NRF_3_RESC0201_L
C6, C14, C20, C21: 4.7μF; NORDIC_NRF_3_RESC0402_L
C9: 820pF; NORDIC_NRF_3_RESC0201_L
C10, C13, C22: N.C.; NORDIC_NRF_3_RESC0201_L
C11: 100pF; NORDIC_NRF_3_RESC0201_L
C15: 1.0μF; NORDIC_NRF_3_RESC0402_L
C16: 47nF; NORDIC_NRF_3_RESC0201_L
C23, C27, C34, C42: 0.1uF; GRM011R60J152KE01L_2_CAPC0201X13N
C24: 10uF; NORDIC_NRF_3_RESC0402_L
C25, C33: 22uF; NORDIC_NRF_3_RESC0402_L
C29, C30, C31, C32, C37: 1uF; GRM011R60J152KE01L_2_CAPC0201X13N
C38: 10uF; GRM011R60J152KE01L_2_CAPC0201X13N
C39: 1uF; NORDIC_NRF_3_RESC0402_L
C43: 4.7uF; PERFECT_0402_0402
D1, D2, D5: MBR0530; ESP32_C6_LIBRARY_5_SOD3716X135N
D3: USBLC6-2SC6Y; ESP32_C6_LIBRARY_3_SOT95P280X145-6N
DMG2305UX-7: 20V/4.2A/52mΩ/1.4W; ESP32_C6_LIBRARY_4_ESP32_C6_LIBRARY_4_ESP32_C6_LIBRARY_4_ES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
EPD_C1, EPD_C2, EPD_C6, EPD_C7, EPD_C8, EPD_C9, EPD_C10, EPD_C11, EPD_C12: 1uF/50V; PERFECT_0402_0402
EPD_C5: 0.1uF/50V; NORDIC_NRF_3_RESC0201_L
IC1: BQ25180YBGR; BQ25180YBGR_BGA8C40P2X4_100X155X50
IC2: DRV2605YZFR; DRV2605YZFR_BGA9C50P3X3_144X144X62
IC3: BMA421; BMA423_BMA423
IC9: RT6160AWSC; RT6160AWSC_BGA15C40P3X5_140X230X60
J1: 503480-2400_503480-2400; 503480-2400_5034802400
J2: TC2030-IDC; TC2030-IDC_TC2030IDC
J4: KH-TYPE-C-16P; KH-TYPE-C-16P_KINGHELM_KH-TYPE-C-16P
L1: 3.9nH; NORDIC_NRF_2_RESC0402_L
L2: 10μH; NORDIC_NRF_2_RESC0402_L
L3: 15nH; NORDIC_NRF_2_RESC0402_L
L5: 68uH; ESP32_C6_LIBRARY_2_IND_4828-WE-TPC_WRE
L7: FTC252012SR47MBCA; MLP2016SR47MT0S1_INDC2016X100N
Q3: SI1308EDL-T1-GE3; ESP32_C6_LIBRARY_6_SOT65P210X110-3N
R1_EP_DR: 0.47; CPF0201D7K68C1_0201
R1_USB, R2_USB: 5K1; CPF0201D7K68C1_0201
R2, R3, R4: 0; CPF0201D7K68C1_0201
R2_EP_DR, R5, R7, R8, R9: 10K; CPF0201D7K68C1_0201
R17: 3K3; ERA-1AEB3401C_0201
R18: 3k3; ERA-1AEB3401C_0201
R_PWR_EPD: 10K; CPF0201D7K68C1_0201
R_TYPE_SEL: 2.2; CPF0201D7K68C1_0201
SJ1: ESP32_C6_LIBRARY_7_JUMPER_SJ
SW_DN: 2025-10-22_07-23-44_LIBRARY_EVP-AKE31ASW_EVP-AKE3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; 2025-10-22_07-23-44_LIBRARY_SW_EVP-AKE31A_PAN
SW_ENT: 2025-10-22_07-23-44_LIBRARY_EVP-AKE31ASW_EVP-AKE3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; 2025-10-22_07-23-44_LIBRARY_SW_EVP-AKE31A_PAN
SW_UP: 2025-10-22_07-23-44_LIBRARY_EVP-AKE31ASW_EVP-AKE3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; 2025-10-22_07-23-44_LIBRARY_SW_EVP-AKE31A_PAN
TP_3.3V, TP_3V3: HECTOR_WATCH_1_TPTP20R; HECTOR_WATCH_1_TP20R
TP_GND: HECTOR_WATCH_1_TPTP20R; HECTOR_WATCH_1_TP20R
TP_ON: HECTOR_WATCH_1_TPTP20R; HECTOR_WATCH_1_TP20R
TP_OP: HECTOR_WATCH_1_TPTP20R; HECTOR_WATCH_1_TP20R
TP_RESET: HECTOR_WATCH_1_TPTP20R; HECTOR_WATCH_1_TP20R
TP_SCL: HECTOR_WATCH_1_TPTP20R; HECTOR_WATCH_1_TP20R
TP_SDA: HECTOR_WATCH_1_TPTP20R; HECTOR_WATCH_1_TP20R
TP_SWDCLK: HECTOR_WATCH_1_TPTP20R; HECTOR_WATCH_1_TP20R
TP_SWIO: HECTOR_WATCH_1_TPTP20R; HECTOR_WATCH_1_TP20R
TP_SWO: HECTOR_WATCH_1_TPTP20R; HECTOR_WATCH_1_TP20R
TP_VBAT: HECTOR_WATCH_1_TPTP20R; HECTOR_WATCH_1_TP20R
TP_VBAT_GND: HECTOR_WATCH_1_TPTP20R; HECTOR_WATCH_1_TP20R
TP_VREG: HECTOR_WATCH_1_TPTP20R; HECTOR_WATCH_1_TP20R
U1: NRF52840_QF; NORDIC_NRF_4_AQFN50P700X700X85_HS-74N
U3: MAX17048G+T10; ESP32_C6_LIBRARY_SON50P200X200X80-9N
X1: 32MHz; NORDIC_NRF_BT-XTAL_2016_N
X2: 32.768kHz; NORDIC_NRF_1_XTAL_3215_N

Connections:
3V3/1.7D: C34.2, DMG2305UX-7.2 (S), IC2.C2 (VDD), R5.2, R7.2, R8.2, R_PWR_EPD.2
3V3/2.4A: C6.1, C7.1, C8.1, C12.1, C14.1, C19.1, C25.1, C33.1, IC3.3 (VDDIO), IC3.7 (VDD), IC3.10 (CSB), IC9.E2 (VOUT_1), IC9.E3 (VOUT_2), J2.1, R17.1, R18.1, TP_3.3V.TP, TP_3V3.TP, U1.P$A22 (VDD), U1.P$AD14 (VDD), U1.P$AD23 (VDD), U1.P$B1 (VDD), U1.P$W1 (VDD), U1.P$Y2 (VDDH)
ALERT/1.6C: U3.5 (!ALERT)
ALERT/2.5C: U1.P$J24 (P0.10/NFC2)
D+/1.5D: D3.4 (I/O2_2)
D+/2.7D: U1.P$AD6 (D+)
D-/1.5D: D3.6 (I/O1_2)
D-/2.7D: U1.P$AD4 (D-)
DEC1: C5.1, U1.P$C1 (DEC1)
DEC3: C11.1, U1.P$D23 (DEC3)
DEC4_6: C10.1, C15.1, C16.1, L3.2, U1.P$B5 (DEC4), U1.P$E24 (DEC6)
DN: D3.1 (I/O1_1), J4.A7 (DN1), J4.B7 (DN2)
DP: D3.3 (I/O2_1), J4.A6 (DP1), J4.B6 (DP2)
EPD_3V3: C1-EP-DR.1, DMG2305UX-7.3 (D), EPD_C5.2, J1.15, J1.16, L5.2
EPD_BUSY/1.5D: J1.9
EPD_BUSY/2.2D: U1.P$AD12 (P0.17)
EPD_CS/1.4C: J1.12
EPD_CS/2.2D: U1.P$K2 (P0.05/AIN3)
EPD_DC/1.5D: J1.11
EPD_DC/2.2D: U1.P$AD10 (P0.15)
EPD_RST/1.5D: J1.10
EPD_RST/2.2D: U1.P$AC11 (P0.16)
GDR: J1.2, Q3.1 (G), R2_EP_DR.2
GND: C1.2, C1-EP-DR.2, C2.2, C3.2, C4.2, C5.2, C6.2, C7.2, C8.2, C9.2, C10.2, C11.2, C12.2, C13.2, C14.2, C15.2, C16.2, C17.1, C18.1, C19.2, C20.2, C21.2, C22.2, C23.2, C24.1, C25.2, C27.1, C29.1, C30.1, C31.1, C32.1, C33.2, C34.1, C37.1, C38.1, C39.2, C42.2, C43.2, D1.1 (K), D3.2 (GND), EPD_C1.2, EPD_C2.2, EPD_C5.1, EPD_C6.2, EPD_C7.2, EPD_C8.2, EPD_C9.2, EPD_C10.2, EPD_C11.2, EPD_C12.2, IC1.D2 (GND), IC2.B1 (IN/TRIG), IC2.B3 (GND), IC3.8 (GNDIO), IC3.9 (GND), IC9.B1 (VSEL), IC9.C1 (AGND), IC9.C2 (PGND_1), IC9.C3 (PGND_2), J1.8, J1.17, J1.MP1, J1.MP2, J2.3, J2.5, J4.A1_B12 (GND), J4.A12_B1 (GND), J4.SH1 (SHIELD), J4.SH2 (SHIELD), J4.SH3 (SHIELD), J4.SH4 (SHIELD), R1_USB.1, R2_EP_DR.1, R2_USB.2, R3.1, R9.1, R_TYPE_SEL.1, SJ1.1, SW_DN.1, SW_ENT.1, SW_UP.1, TP_GND.TP, TP_VBAT_GND.TP, U1.P$74 (VSS_PAD), U1.P$75 (VSS_PAD), U1.P$76 (VSS_PAD), U1.P$77 (VSS_PAD), U1.P$78 (VSS_PAD), U1.P$79 (VSS_PAD), U1.P$80 (VSS_PAD), U1.P$81 (VSS_PAD), U1.P$82 (VSS_PAD), U1.P$83 (VSS_PAD), U1.P$84 (VSS_PAD), U1.P$85 (VSS_PAD), U1.P$86 (VSS_PAD), U1.P$87 (VSS_PAD), U1.P$88 (VSS_PAD), U1.P$89 (VSS_PAD), U1.P$90 (VSS_PAD), U1.P$B7 (VSS), U1.P$F23 (VSS_PA), U3.1 (CTG), U3.4 (GND), U3.6 (QSTRT), U3.9 (EP), X1.2, X1.4
HAPTIC-EN/1.4C: IC2.A1 (EN)
HAPTIC_EN/2.6A: U1.P$U1 (P0.12)
IMU_INT1: IC3.5 (INT1), U1.P$N1 (P0.08)
IMU_INT2: IC3.6 (INT2), U1.P$P2 (P1.08)
LX1: IC9.B2 (SW1_1), IC9.B3 (SW1_2), L7.1
LX2: IC9.D2 (SW2_1), IC9.D3 (SW2_2), L7.2
MOSI/1.5B: J1.14
MOSI/2.2D: U1.P$B13 (P0.03/AIN1)
unnamed: C3.1, L1.1, U1.P$H23 (ANT)
unnamed: IC9.D1 (SCL), R4.2
unnamed: C17.2, U1.P$D2 (P0.00/XL1), X2.1
unnamed: IC9.E1 (SDA), R2.2
unnamed: C18.2, U1.P$F2 (P0.01/XL2), X2.2
unnamed: L2.1, U1.P$B3 (DCC)
unnamed: IC1.D1 (TS/MR), R9.2
unnamed: L2.2, L3.1
unnamed: C2-EP-DR.1, D1.2 (A), D5.1 (K)
unnamed: C1.1, U1.P$B24 (XC1), X1.1
unnamed: IC3.1 (SDO), R3.2
unnamed: C2-EP-DR.2, D2.2 (A), L5.1, Q3.3 (D)
unnamed: C9.1, U1.P$N24 (DEC5)
unnamed: C2.1, U1.P$A23 (XC2), X1.3
unnamed: R1_EP_DR.1, R_TYPE_SEL.2, SJ1.2
unnamed: C32.2, IC2.A2 (REG)
unnamed: C20.1, U1.P$AC5 (DEC3V3)
unnamed: J4.B5 (CC2), R2_USB.1
unnamed: J4.A5 (CC1), R1_USB.2
unnamed: EPD_C2.1, J1.4
unnamed: EPD_C1.1, J1.5
unnamed: EPD_C6.1, J1.18
unnamed: EPD_C7.1, J1.19
unnamed: C13.1, U1.P$A18 (DEC2)
unnamed: EPD_C8.1, J1.20
unnamed: EPD_C9.1, J1.21
unnamed: EPD_C10.1, J1.22
unnamed: EPD_C11.1, J1.23
unnamed: EPD_C12.1, J1.24
OUT+: IC2.A3 (OUT+), TP_OP.TP
OUT-: IC2.C3 (OUT-), TP_ON.TP
P0.04: U1.P$J1 (P0.04/AIN2)
P0.09: U1.P$L24 (P0.09/NFC1)
P0.13/1.5D: C30.2, R5.1, SW_UP.2
P0.13/2.6C: U1.P$AD8 (P0.13)
P0.14/1.5D: C31.2, R8.1, SW_ENT.2
P0.14/2.7C: U1.P$AC9 (P0.14)
P0.19: U1.P$AC15 (P0.19)
P0.20: U1.P$AD16 (P0.20)
P0.21: U1.P$AC17 (P0.21)
P0.22: U1.P$AD18 (P0.22)
P0.23: U1.P$AC19 (P0.23)
P0.24: U1.P$AD20 (P0.24)
P0.25: U1.P$AC21 (P0.25)
P0.26: U1.P$G1 (P0.26)
P0.27: U1.P$H2 (P0.27)
P0.28: U1.P$B11 (P0.28/AIN4)
P0.29: U1.P$A10 (P0.29/AIN5)
P0.30: U1.P$B9 (P0.30/AIN6)
P0.31: U1.P$A8 (P0.31/AIN7)
P1.01/1.6C: DMG2305UX-7.1 (G), R_PWR_EPD.1
P1.01/2.4B: U1.P$Y23 (P1.01)
P1.02/1.6C: C29.2, R7.1, SW_DN.2
P1.02/2.8C: U1.P$W24 (P1.02)
P1.03: U1.P$V23 (P1.03)
P1.04: U1.P$U24 (P1.04)
P1.05: U1.P$T23 (P1.05)
P1.06: U1.P$R24 (P1.06)
P1.07: U1.P$P23 (P1.07)
P1.09: U1.P$R1 (P1.09)
P1.10: U1.P$A20 (P1.10)
P1.11: U1.P$B19 (P1.11)
P1.12: U1.P$B17 (P1.12)
P1.13: U1.P$A16 (P1.13)
P1.14: U1.P$B15 (P1.14)
P1.15: U1.P$A14 (P1.15)
PMIC_INT: IC1.A1 (!INT), U1.P$T2 (P0.11)
PREVGH: D2.1 (K)
PREVGL: D5.2 (A)
RESE: J1.3, Q3.2 (S), R1_EP_DR.2
RESET: J2.6, TP_RESET.TP, U1.P$AC13 (P0.18/RESET)
RF: ANT1.1 (FEED), C4.1, C22.1, L1.2
SCK/1.5B: J1.13
SCK/2.2D: U1.P$A12 (P0.02/AIN0)
SCL/1.4C: IC2.C1 (SCL), U3.7 (SCL)
SCL/2.4C: IC1.B1 (SCL), IC3.12 (SCX), R4.1, R17.2, TP_SCL.TP, U1.P$M2 (P0.07)
SDA/1.4C: IC2.B2 (SDA), U3.8 (SDA)
SDA/2.4C: IC1.C1 (SDA), IC3.2 (SDX), R2.1, R18.2, TP_SDA.TP, U1.P$L1 (P0.06)
SWDCLK: J2.4, TP_SWDCLK.TP, U1.P$AA24 (SWDCLK)
SWDIO: J2.2, TP_SWIO.TP, U1.P$AC24 (SWDIO)
SWO: TP_SWO.TP, U1.P$AD22 (P1.00)
VBAT/1.2A: C27.2, TP_VBAT.TP, U3.2 (CELL), U3.3 (VDD)
VBAT/2.5C: C37.2, IC1.C2 (BAT)
VBUS/1.5D: C42.1, C43.1, D3.5 (VBUS), J4.A4_B9 (VBUS), J4.A9_B4 (VBUS)
VBUS/2.6D: C21.1, C38.2, IC1.A2 (IN), U1.P$AD2 (VBUS)
VREG: C23.1, C24.2, C39.1, IC1.B2 (SYS), IC9.A1 (EN), IC9.A2 (VIN_1), IC9.A3 (VIN_2), TP_VREG.TP

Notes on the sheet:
LiPo Charger
DC/DC
IMU
SWD
E-Paper Drive Circuit
E-Paper Display Connector
Fuel Gauge
Haptic Driver
Buttons
USB C Connector & ESD Protection

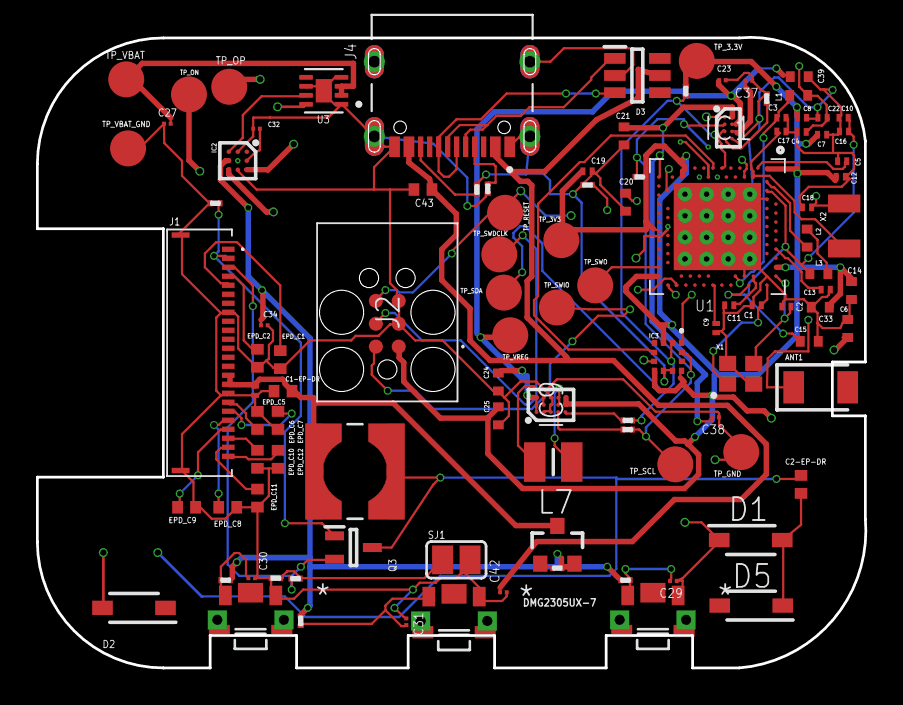
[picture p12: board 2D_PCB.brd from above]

Board: 4 copper layers, 46.0 x 35.0 mm, 105 parts (0 on the bottom side), 65 nets.

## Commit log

2026-04-10 Added project first iteration
    [2D_PCB.brd, PCB.csv, PnP_PCB_front.csv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]
2026-04-17 Added Project Second Iteration
    [2D_PCB.brd, Schematic.sch]
2026-04-17 Changed 2D PCB Photo
2026-04-17 Changed Schematic.pdf

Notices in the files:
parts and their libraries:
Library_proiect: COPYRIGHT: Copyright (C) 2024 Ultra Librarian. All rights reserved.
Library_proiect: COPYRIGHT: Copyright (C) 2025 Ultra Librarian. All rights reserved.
